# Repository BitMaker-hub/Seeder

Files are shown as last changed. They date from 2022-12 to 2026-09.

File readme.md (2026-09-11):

# SEEDER - Sovereign seed generator

Un dispositivo DIY que te permite crear tus propias semillas de Bitcoin en cuestión
de segundos, sin depender de nadie ni de nada para salvaguardar tus fondos.

Con la SEEDER puedes hacer el proceso **semilla moneda**, generar entropía con
**dados**, y **calcular la última palabra de tu semilla sin esfuerzo**, además de
exportarla mediante un código QR.

Todo ello gracias a la genial idea de @Lunaticoin y mi trabajo.

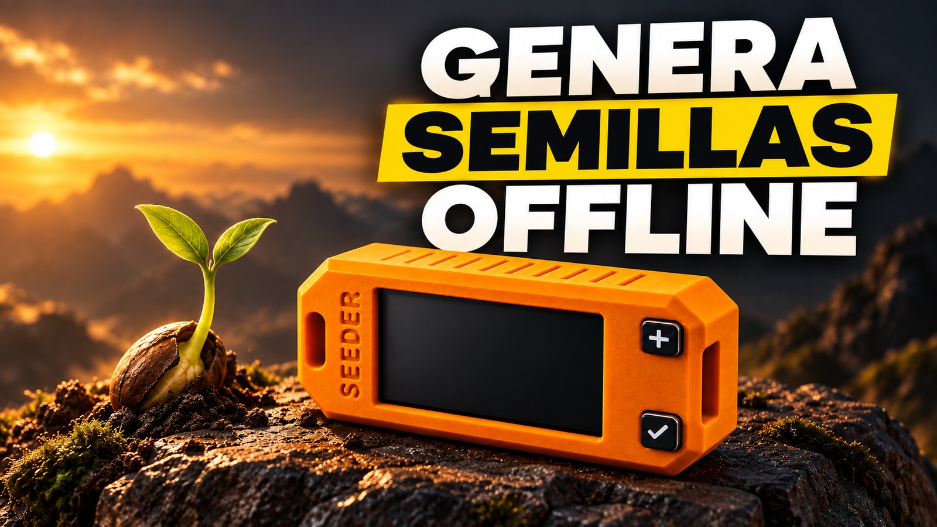
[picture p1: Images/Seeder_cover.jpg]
SEEDER, genera semillas offline


## La SEEDER no genera entropía

Esto es lo que hace distinta a la v2: **el dispositivo no tiene generador de números
aleatorios**. La entropía la pones tú, con una moneda o con un dado, y la SEEDER se
limita a hacer las cuentas de BIP39 delante de ti.

Y esas cuentas las puedes rehacer por tu lado. La SEEDER te enseña la entropía en
hexadecimal en la pantalla `Entropy (hex)`. Con ese hex y cualquier herramienta BIP39
offline obtienes exactamente las mismas palabras. Si no coinciden, tira el aparato.

| Modo | Entradas | Entropía |
|---|---|---|
| Moneda | 128 tiradas (12 palabras) / 256 (24) | los bits, tal cual, sin pasar por ningún hash |
| Dado | 50 tiradas (12 palabras) / 99 (24) | `SHA-256` de los dígitos en ASCII |

El modo dado usa el mismo esquema que la Coldcard, así que puedes verificarlo desde
un terminal:

```bash
printf '3141592653...' | sha256sum
```

Con 24 palabras se usan los 32 bytes del hash; con 12 palabras, los **16 primeros**
(los 32 primeros caracteres del hex). Es lo mismo que hace la Coldcard.

Y el modo moneda no aplica ningún hash: los bits que lanzas **son** la entropía. Eso
te permite además meter una entropía que ya tengas y dejar que la SEEDER te calcule
la última palabra con su checksum.

## Requisitos

Cualquiera de las dos placas:

| Placa | Pantalla | Binario |
|---|---|---|
| LilyGO TTGO T-Display (ESP32) | 240x135 | `seeder-tdisplay-merged.bin` |
| LilyGO T-Display-S3 (ESP32-S3) | 320x170 | `seeder-tdisplay-s3-merged.bin` |

Y un cable USB-C.

Opcionalmente admite una LiPo por el conector JST. La placa no trae interruptor,
pero **sí se puede apagar por firmware**: cómo hacerlo, y qué esperar del consumo
en reposo, está en [HARDWARE.md](HARDWARE.md).

## Instalación

Todo sale de la [última release](https://github.com/BitMaker-hub/Seeder/releases).
Hay dos caminos: uno cómodo y otro comprobable. Elige según lo que te juegues.

### Vía rápida — desde el navegador

Descarga `seeder-firmware-merged.bin` y flaséalo con
[esptool-js](https://espressif.github.io/esptool-js/) en el offset **0x0**.
Un solo archivo, nada que instalar.

> Cómodo, pero estás confiando en que la página te sirvió el binario correcto.
> Para una semilla de verdad, haz también la comprobación de abajo.

### Vía manual — desde el terminal, y verificable

Descarga la release entera, incluido el `SHA256SUMS`, y comprueba que lo que te
has bajado es lo que la CI publicó:

```bash
sha256sum -c SHA256SUMS
```

Flashea:

```bash
esptool.py --chip esp32 --port /dev/ttyUSB0 --baud 460800   write_flash -z 0x0 seeder-firmware-merged.bin
```

Y comprueba que el chip contiene de verdad ese binario:

```bash
esptool.py --port /dev/ttyUSB0 --no-stub verify_flash 0x0 seeder-firmware-merged.bin
```

En Windows el puerto es `COM3` o similar. Ese último paso es el que importa y
está explicado en [SECURITY.md](SECURITY.md): con `--no-stub` la aplicación de la
SEEDER ni se ejecuta, responde el bootloader de la ROM del chip, así que un
firmware manipulado no puede mentir sobre lo que hay en la flash.

## Compilar desde fuente

```bash
pio run -e seeder
```

Las librerías (`uBitcoin`, `TFT_eSPI`) van fijadas dentro de `lib/` a propósito:
un generador de semillas debe compilar igual hoy que dentro de cinco años.

## Controles

Dos botones y nada más. **MOVE** es el de arriba y **OK** el de abajo.

| Dónde estás | MOVE | OK |
|---|---|---|
| Menú y elección de palabras | cambia la opción | acepta |
| Lanzando la moneda | cara | cruz |
| Tirando el dado | 1 → 6 | acepta la tirada |
| Leyendo la semilla | página siguiente | página anterior |
| Última página (`Exit`) | vuelve a la primera | mantener para salir y borrar |

Durante la captura, **mantener OK tres segundos vuelve al menú** y borra lo que
llevaras metido: si te has equivocado en la tirada 40 de 99 no hace falta
desenchufar el aparato. A los ~1,2 s aparece el aviso con una barra que se llena;
si sueltas antes, esa pulsación no cuenta como cara, cruz ni tirada.

## Llevarla a Sparrow

La SEEDER exporta dos QR distintos, y **no dan el mismo poder**:

| Pantalla | Qué lleva | Quien lo escanee |
|---|---|---|
| `Export` | las 12 o 24 palabras | **puede gastar** |
| `Watch only` | el zpub de cuenta | sólo ve el saldo |

**Sólo lectura** — es el que puedes escanear con el ordenador delante:

1. `File > New Wallet…`, le pones nombre y `Create Wallet`.
2. Se abre en *Settings* con **Single Signature** y **Native Segwit (P2WPKH)**
   ya puestos. Déjalos: son justo los de la SEEDER.
3. En *Keystores*, el icono del **ojo**, `Watch Only Wallet`.
4. En la fila `xpub:`, el botón de la **cámara**, y le enseñas el QR.
5. La SEEDER te muestra la huella maestra en esa misma pantalla. Cópiala en
   *Master fingerprint*, que Sparrow lo deja en `00000000` y ese cero acaba
   metido en cada PSBT que construya.
6. `Apply`.

> El botón de QR que hay junto al campo `Descriptor:` **no** sirve para esto:
> con una clave suelta no hace nada y no avisa. Tiene que ser el de la fila
> `xpub:`.

**La semilla**, si de verdad la quieres importar: `BIP39 keystore`, la **flecha
del desplegable** junto a `Use 24 Words`, y ahí dentro `Scan QR…`. No hay botón
visible y no está documentado. Necesita Sparrow **1.7.7 o posterior**.

Pero piénsatelo: meter las palabras en un ordenador conectado tira por tierra
todo lo demás. Para mirar el saldo te basta el zpub.

## Verificación

No te fíes de la SEEDER: compruébala. La pantalla `Entropy (hex)` te enseña los
bytes de los que salieron tus palabras, y con ese hex y cualquier herramienta BIP39
**offline** puedes rehacer las cuentas. Si no coinciden, no uses el aparato.

Hazlo con **tu propia entropía**, no con los vectores publicados: un firmware
malicioso reconoce las tiradas de prueba y se porta bien sólo ahí.

El modelo de amenazas completo, y qué no cubre, está en [SECURITY.md](SECURITY.md).

> La semilla nunca sale del dispositivo ni se escribe en flash: sólo vive en RAM y
> desaparece al desconectarlo. El firmware tampoco imprime nada por el puerto serie.

## TUTORIAL

Tutorial completo en YouTube:

Ver video aquí (https://youtu.be/2K7ztWxtyY8)

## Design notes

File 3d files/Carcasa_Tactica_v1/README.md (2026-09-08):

# SEEDER — carcasa táctica v1

Carcasa para **LilyGO TTGO T-Display (ESP32)** con hueco para batería, cierre por
clips y anilla para colgar. Todas las cotas de la placa están sacadas del STEP
oficial `T-Display.step`, no estimadas.

**Exterior: 30.6 × 66.0 × 17.4 mm** · ~16 g de PLA el juego completo.

## Piezas

| Fichero | Qué es | Cantidad |
|---|---|---|
| `Seeder_CUERPO.stl` | Cuerpo frontal (pantalla, botones, USB, anilla) | 1 |
| `Seeder_TAPA.stl` | Tapa trasera con clips y bolsillo de batería | 1 |
| `Seeder_BOTONES_x2.stl` | Los dos pulsadores (`+` y check) | 1 juego |
| `Seeder_BOTONES_x2_giro_opuesto.stl` | Los mismos con los iconos girados 180° | alternativa |

### Por qué hay dos juegos de botones

El firmware arranca la UI en **landscape** (`setRotation(1)`, 240×135), o sea que
el aparato se lee girado 90° respecto a la carcasa. Los iconos van grabados en esa
orientación, pero según hacia qué lado gires el aparato al usarlo, el check queda
derecho o del revés. Imprime el juego que corresponda; el `+` da igual.

## Impresión (Bambu Lab P1S / P2S / H2S)

| Ajuste | Valor |
|---|---|
| Material | PLA (o PETG si lo quieres más resistente al calor) |
| Boquilla / capa | 0.4 mm / 0.2 mm |
| Perímetros | 3 |
| Relleno | 20 % giroide |
| Soportes | **ninguno** |
| Balsa/brim | no hace falta |

**Orientación en la placa:**

- **Cuerpo**: cara frontal (la de la pantalla) **contra la cama**. Así el grabado
  del SEEDER y los nervios salen limpios, y las cavidades quedan hacia arriba.
  Si usas placa texturizada, la cara vista sale con acabado mate tipo equipo militar.
- **Tapa**: cara exterior contra la cama. Los clips y las paredes de la batería
  quedan hacia arriba, sin voladizos.
- **Botones**: cara vista (la del icono) contra la cama.

Los únicos puentes son el techo de la abertura del USB (12.4 mm) y el de las
cuatro ventanas de clip (7 mm). Ambos los hace cualquier Bambu sin problema.

## Montaje

1. Mete la placa en el cuerpo **por detrás**, con la pantalla mirando a la ventana.
   Apoya sobre la repisa perimetral de 2 mm.
2. Coloca los dos botones por delante, desde fuera. Encajan a presión: la pestaña
   queda atrapada entre la placa frontal y la PCB, así que **no se caen una vez
   cerrada la tapa**.
3. Conecta la batería al JST y colócala en el bolsillo de la tapa. El cable sale
   por el hueco de 11.2 mm del lado del USB.
4. Cierra la tapa presionando hasta oír los cuatro clics.

**Para abrir**: hay una muesca de palanca en el canto del USB. Una uña o una púa
de guitarra bastan.

## Batería

Cabe hasta **21 × 40 × 6.6 mm**. Una LiPo 602040 (500 mAh) entra holgada. Sujétala
con un trozo de cinta de doble cara al fondo del bolsillo para que no baile.

## Comprobado

- Las tres piezas son **watertight** (malla cerrada, lista para laminar).
- Encaje verificado contra los 655 sólidos del STEP de la placa: interferencia
  máxima **0.010 mm**, y sólo en el plano donde la PCB apoya sobre su repisa.
  Se descuenta automáticamente la envolvente de cada componente frontal, así que
  ni el pulsador de reset ni los SMD del borde rozan.
- Los botones llevan 0.05 mm de precarga contra el pulsador SMD: hacen contacto
  sin dejarlo pulsado.

## ⚠️ Verificar antes de imprimir la serie

El STEP de LilyGO **no incluye ni el conector USB ni el módulo ESP32**. Por eso:

- La abertura del USB va deliberadamente holgada: **12.4 mm de ancho × 4.4 de alto**
  (z 4.5–8.9), que vale tanto para micro-USB como para USB-C. **Mide la tuya** y
  ajusta `USB_W`, `USB_Z0` y `USB_Z1` en `seeder_case.py` si quieres que ajuste fino.
- El hueco para componentes traseros es de 3.8 mm, suficiente para el ESP32-WROOM
  (3.1 mm). Si tu placa lleva algo más alto por detrás, sube `BACK_CLR`.

Imprime **una** unidad y prueba el encaje antes de tirar de serie.

## Regenerar / modificar

Todo es paramétrico. Los parámetros están arriba del todo de `seeder_case.py`.

```bash
py -m pip install build123d trimesh manifold3d shapely numpy rtree
```

```bash
py seeder_case.py
```

- `extract_clearance.py` regenera `components.json` desde el STEP (sólo hace falta
  si cambias de placa).
- `fitcheck.py` vuelve a comprobar que la placa no choca con nada.

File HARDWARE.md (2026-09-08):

# La SEEDER con batería

La T-Display admite una LiPo por su conector JST 1.25, pero **no trae interruptor**:
la enchufas y está encendida para siempre. Este documento recoge lo que hay que
saber para montarla con batería, incluida una función de la placa que no está
documentada en ningún sitio.

---

## Sí se puede apagar: PWR_EN es GPIO14

La T-Display tiene un MOSFET que corta la batería, y el ESP32 puede accionarlo.
Sale del [esquemático oficial](https://github.com/Xinyuan-LilyGO/TTGO-T-Display/blob/master/schematic/ESP32-TFT(6-26).pdf),
donde la red `PWR_EN` está en el **pin 17 del módulo, `MTMS/IO14`**:

```
PWR_EN (GPIO14) ──D6──┐
                      ├── R25 10K ──► base Q3 (PMBT3904)     R27 100K a GND
VBUS ─────────────D1──┘
                            colector Q3 ── R26 1K ──► puerta de Q4 y Q6

BAT ──► Q4 (SI2301, canal P) ──► IN del AP2112K-3.3V ──► VDD3V3
              R28 100K entre la puerta y el lado del regulador
```

`Q4` es el interruptor de la batería. Su puerta la manda `Q3`, que conduce si hay
`VBUS` **o** si `PWR_EN` está alto.

En la práctica:

```cpp
pinMode(14, OUTPUT);
digitalWrite(14, HIGH);   // engancha la alimentación al arrancar
...
digitalWrite(14, LOW);    // corta la batería
```

### Dos advertencias

**Por USB no se puede apagar, y esto es seguro.** `D1` mete VBUS directamente en
la base de `Q3`, así que mientras haya cable, `Q3` conduce pase lo que pase con
GPIO14. El corte sólo tiene efecto con la placa alimentada sólo por batería.

**El enganche es flojo, y esto está sin verificar.** `R28` lleva la puerta de `Q4`
al lado del regulador, no al de la batería. Eso hace que la placa arranque sola al
conectar la LiPo, pero también que al soltar `PWR_EN` la puerta suba siguiendo al
propio raíl que está alimentando: puede cortar limpiamente o quedarse en una zona
intermedia y rearrancar. En el repo de LilyGO hay un
[hilo abierto](https://github.com/Xinyuan-LilyGO/TTGO-T-Display/issues/6) de alguien
que reporta justo eso, sin respuesta.

**Si lo pruebas, cuéntanoslo.** Es la clase de dato que no está escrito en ninguna
parte.

---

## La alternativa segura: un interruptor

Para una unidad que va a estar guardada, lo que no falla es un **interruptor
deslizante en el positivo del JST**. Cero consumo, y en un generador de semillas
"apagado" de verdad vale más que "durmiendo". La carcasa de `3d files/` tiene sitio.

---

## Sueño profundo, y por qué aquí importa

Si no cortas la corriente, la otra vía es el *deep sleep* del ESP32, despertando con
un botón. El detalle que casi todo el mundo se salta: **si no apagas la pantalla se
siguen yendo unos 10 mA** aunque el chip duerma. Hay que apagarla a mano:

```cpp
digitalWrite(TFT_BL, LOW);                    // GPIO4, retroiluminación
tft.writecommand(ST7789_DISPOFF);             // apagar el panel
tft.writecommand(ST7789_SLPIN);               // dormir el controlador
esp_sleep_enable_ext0_wakeup(GPIO_NUM_0, 0);  // despertar con OK
esp_deep_sleep_start();
```

Con eso se llega a **~380 µA**, [medidos por la comunidad](https://www.paleotechnologist.net/?p=5041).
Con una LiPo de 500 mAh son unos **55 días** en reposo, frente a dos días si te
olvidas del panel. No es cero: para meses en un cajón, interruptor.

Los dos botones sirven para despertar. Los pines RTC del ESP32 son
[`0, 2, 4, 12-15, 25-27, 32-39`](https://docs.espressif.com/projects/esp-idf/en/stable/esp32/api-reference/system/sleep_modes.html),
y tanto `GPIO0` como `GPIO35` están dentro.

### Y para este aparato en concreto, dormir es borrar

La documentación de Espressif lo dice de las modalidades de sueño profundo: *las CPU,
la mayor parte de la RAM y todos los periféricos digitales se apagan*. Sólo sobrevive
la memoria RTC, y la SEEDER no guarda nada ahí.

O sea que **entrar en sueño profundo destruye la semilla por hardware**, sin depender
de que el `memzero` del firmware esté bien escrito. Para un aparato cuya premisa es
no fiarse del firmware, eso no es un detalle menor.

---

## Un fallo conocido

Hay un [hilo abierto](https://github.com/Xinyuan-LilyGO/TTGO-T-Display/issues/111)
donde, tras descargar la batería del todo, la placa "olvida" que podía despertar por
GPIO y sólo revive con un reset manual. Sin causa identificada. Tenlo presente si
montas una unidad para dejarla guardada mucho tiempo.

---

## Medir la batería

El divisor de tensión de la batería está en **GPIO34** (`ADC_IN` en el pinout de
LilyGO). No lo usamos, pero está ahí si alguien quiere un indicador de carga.

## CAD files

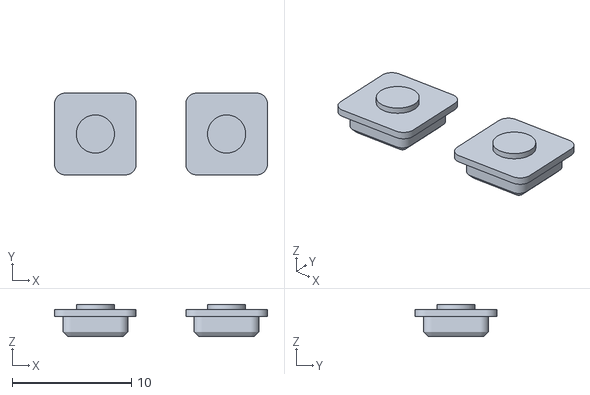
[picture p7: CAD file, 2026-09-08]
3d files/Carcasa_Tactica_v1/Seeder_BOTONES_x2_giro_opuesto.stl
17.9 x 6.85 x 2.70

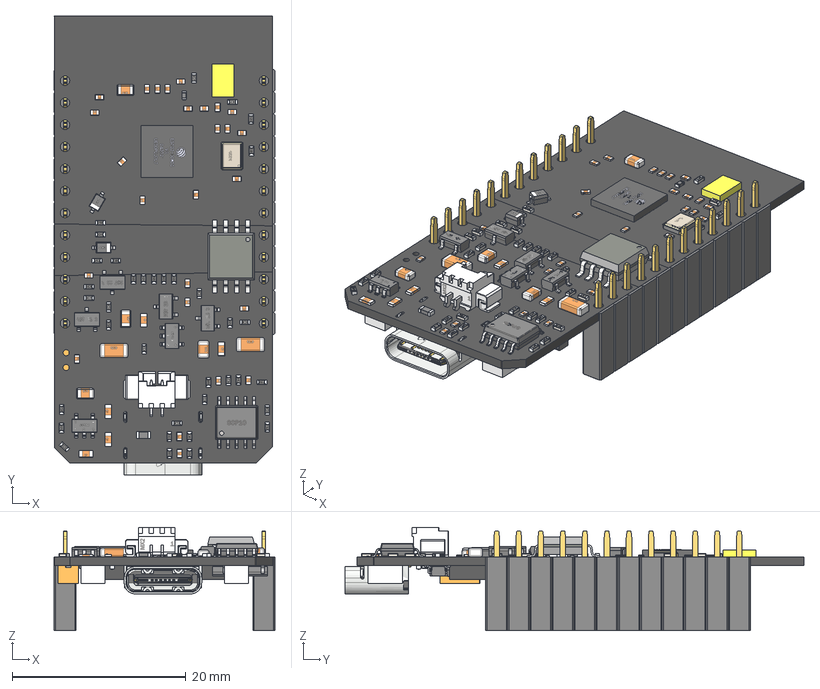
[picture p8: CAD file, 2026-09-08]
3d files/T-Display.step
25.5 x 52.8 x 11.9 mm
Board
User_Library-RES_1005-0402 x 39
SOD323 x 2
C1206 x 2
0402_SMD_Capacitor x 27
SW3dPS-SOIC8_(ATTINY12)
HDR2.54-1P_M x 24
LOGO? x 24
User_Library-SOT23-5_SOT23-5_Connector_Default x 10
User_Library-SOT23-5_SOT23-5_Body_Default x 2
L0402
ESP32
OSC_3225-4
LOGO?0.15
L0603
SOT-23-3 x 7
MOLEX1.25-WS-竘褐 x 2
LOGO?0.25
MOLEX1.25-WS-2P
User_Library-0603_SMD_Capacitor x 7
User_Library-0805_SMD_Capacitor x 4
SOP10_呿极
厚度2.0_宽度0.35的引脚 x 10
Extruded x 5
SOD-123
LOGOﾔｲ｣ｭ｣ｰ.｣ｳ
hmt-usb16f-dip

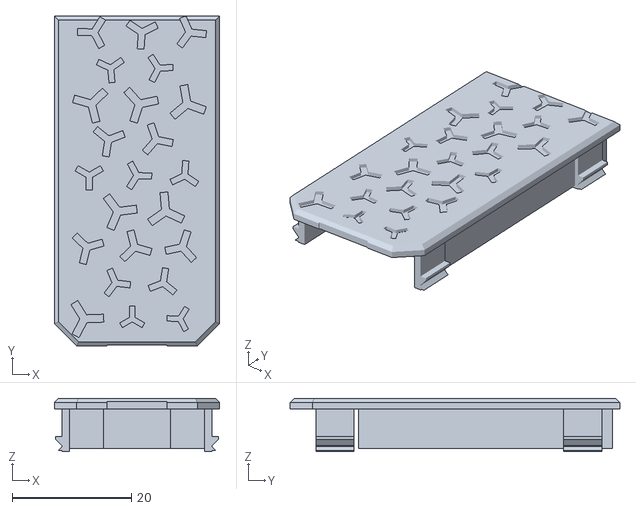
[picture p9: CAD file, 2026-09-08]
3d files/Carcasa_Tactica_v1/Seeder_TAPA.stl
27.7 x 55.3 x 8.90

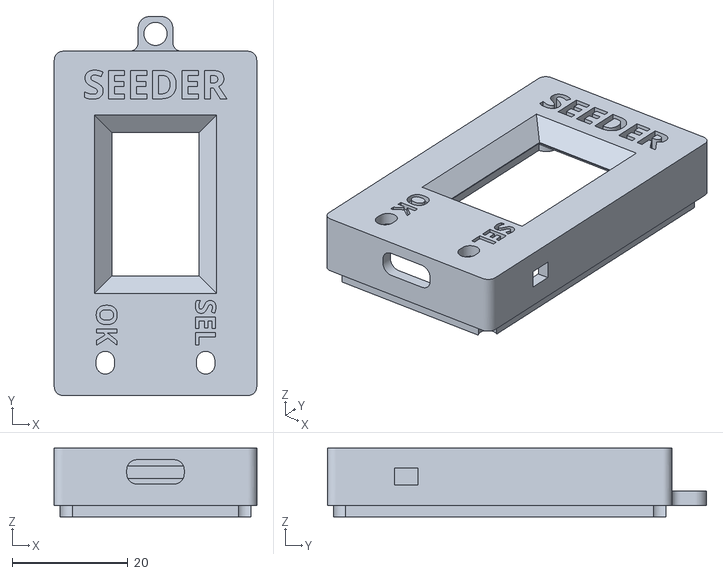
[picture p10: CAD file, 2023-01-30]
3d files/SeederTOP.stl
35.0 x 65.5 x 11.9

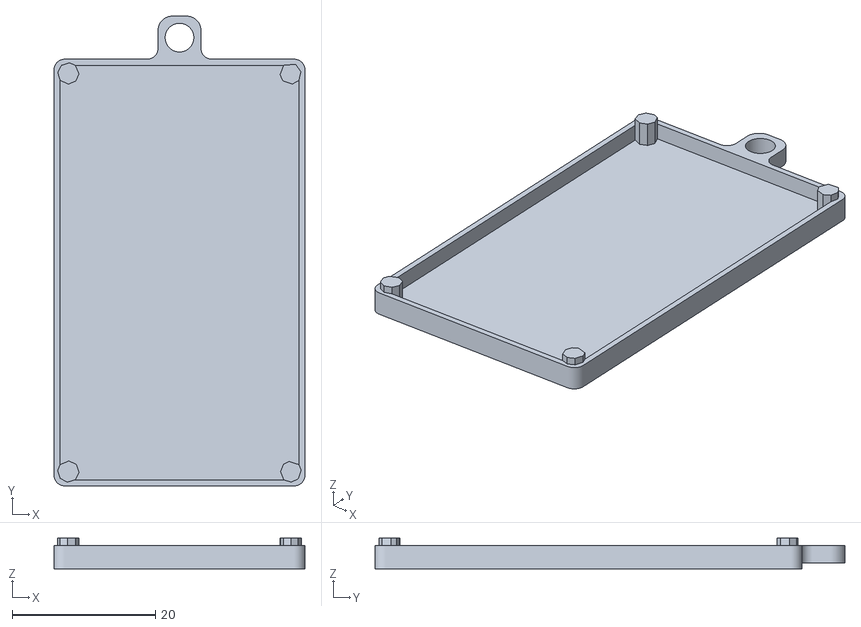
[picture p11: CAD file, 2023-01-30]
3d files/TAPA_SEEDER.stl
35.0 x 65.5 x 4.30

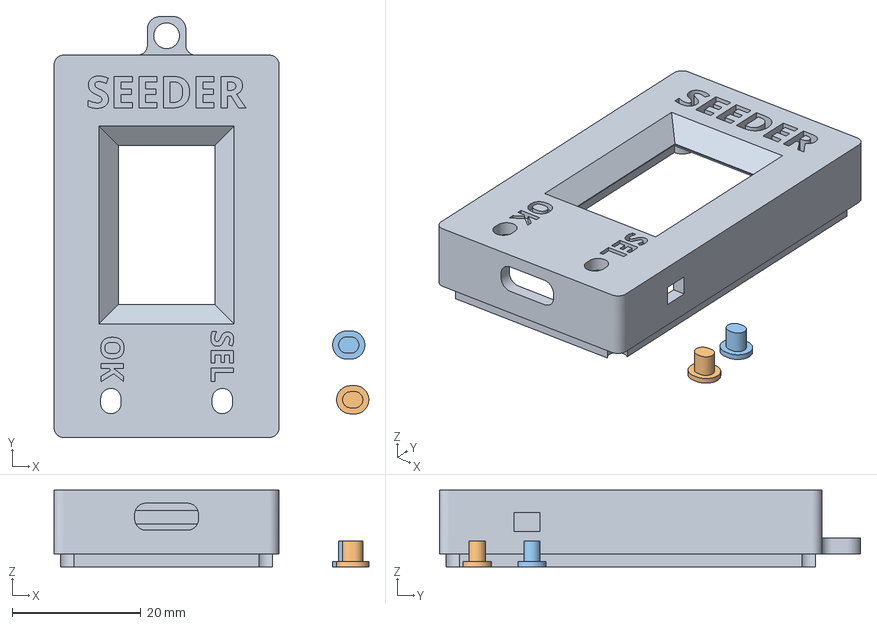
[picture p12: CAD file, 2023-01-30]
3d files/AG_SeederALL.3mf
49.0 x 65.5 x 11.9 mm
SeederTOP.stl
button-2.stl
button-3.stl

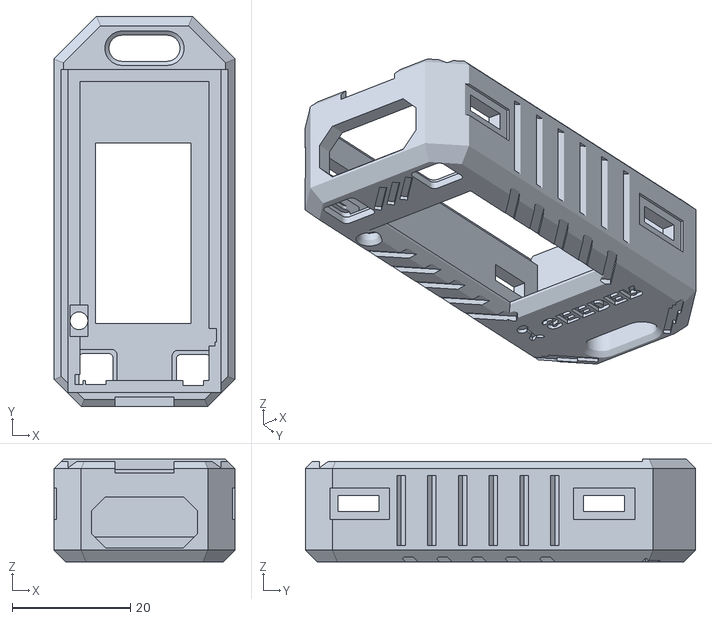
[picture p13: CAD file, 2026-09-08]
3d files/Carcasa_Tactica_v1/Seeder_CUERPO.stl
30.6 x 66.0 x 17.4

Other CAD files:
3d files/Carcasa_Tactica_v1/Seeder_BOTONES_x2.stl

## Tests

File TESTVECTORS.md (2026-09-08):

# Vectores de prueba

Cómo comprobar que tu SEEDER hace las cuentas bien, sin fiarte de ella.

Ninguno de estos vectores es una semilla que debas usar: son entropías
degeneradas, elegidas justamente porque se pueden reproducir a mano.

## Modo moneda — los bits son la entropía

En el modo moneda no hay hash: los bits que lanzas **son** la entropía. Así que
si sacas siempre cruz, la entropía es todo ceros, y eso da el vector de prueba
más conocido de BIP39. Cualquier herramienta del mundo te dará lo mismo.

**12 palabras — 128 tiradas, todas cruz**

```
Entropy (hex)  00000000000000000000000000000000
abandon abandon abandon abandon abandon abandon
abandon abandon abandon abandon abandon about
```

**24 palabras — 256 tiradas, todas cruz**

```
Entropy (hex)  0000...0000  (32 bytes a cero)
abandon x23 art
```

## Modo dado — SHA-256 de las tiradas

El dado siempre vuelve al 1 después de aceptar una tirada, así que **pulsando
sólo OK** metes una tirada de 1 cada vez. 50 veces para 12 palabras, 99 para 24.

Toques cortos: mantener OK más de un segundo no cuenta como tirada, saca el aviso
de `START OVER` y a los tres segundos vuelve al menú.

**12 palabras — 50 unos**

```
$ printf '11111111111111111111111111111111111111111111111111' | sha256sum
3dac51a65ec9fcfc409a1b5f1defe92ba723843118ea511971ab46b36859495f

Entropy (hex)  3DAC51A65EC9FCFC409A1B5F1DEFE92B     <- los 16 primeros bytes
diet glad hat rural panther lawsuit act drop gallery urge where fit
```

**24 palabras — 99 unos**

```
$ printf '111111111111111111111111111111111111111111111111111111111111111111111111111111111111111111111111111' | sha256sum
fa098eb852b2660348b21bb00ad03a49cc177ea07ebe34f46b40baa85313525e

Entropy (hex)  FA098EB852B2660348B21BB00AD03A49CC177EA07EBE34F46B40BAA85313525E
wheel erase puppy pistol chapter accuse carpet drop quote final attend near
scrap satisfy limit style crunch person south inspire lunch meadow enact tattoo
```

## Y con tu semilla de verdad

El mismo procedimiento vale para la semilla que vayas a usar, sin publicarla:
apunta el `Entropy (hex)` que te enseña la SEEDER, mételo en cualquier
herramienta BIP39 **offline** y comprueba que salen las mismas palabras.

Si no salen, no uses el aparato.

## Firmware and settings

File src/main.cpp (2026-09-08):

#include <Arduino.h>
#include "gpio.h"
#include "btc.h"
#include "workflow.h"
#include "GlobalVARS.h"

sWallet myWallet;
sButton btnMove(PIN_MOVE);
sButton btnSelect(PIN_SELECT);
  
void setup() {

#if SEEDER_DEBUG
  Serial.begin(SERIAL_BAUD);                  // UART only exists in debug builds
#endif
  Init_TFT();                                   // Init TFT wallet
  myWallet.State = STATE_INITMENU;
}


void loop() {
  
  while(true){
    /***** Check button state ******/
    btnMove.check();
    btnSelect.check();

    /***** Print menu options ***********/
    switch(myWallet.State){
      case STATE_INITMENU:      doInitMenu(); break;
      case STATE_WORDS:        doMenuWords(); break;
      case STATE_SEED:        doShowSeed(); break;
      case STATE_COINSEED:    doCoinSeed(); break;
      case STATE_DICESEED:    doDiceSeed(); break;
    }
    delay(10);
  }
}

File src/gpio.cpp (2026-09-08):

#include "GlobalVARS.h"
#include "gpio.h"
#include "workflow.h"
#include "ui/ui.h"
#include <TFT_eSPI.h> // Graphics and font library for ST7789 driver chip

/**********************🍃 GLOBAL Vars *******************************/
TFT_eSPI tft = TFT_eSPI();  // Invoke library, pins defined in User_Setup.h
extern sWallet myWallet;
extern sButton btnMove;
extern sButton btnSelect;

/*****************🍃 TFT WORK *********************/

void Init_TFT(void){

#ifdef PIN_POWER_ON
  /* La T-Display-S3 alimenta sus periféricos desde este pin. Si no se pone
     alto ANTES de arrancar el panel, la pantalla no enciende y la placa
     parece muerta: es el fallo clásico de esa placa. */
  pinMode(PIN_POWER_ON, OUTPUT);
  digitalWrite(PIN_POWER_ON, HIGH);
  delay(20);
#endif

  tft.init();
  tft.setRotation(1);
  tft.setSwapBytes(true);   // orden de bytes al volcar imágenes

  ui::splash();

  myWallet.entropySrc = coinEntropy;
  drawInitMenu();
}

/*****************🍃 BUTTON DETECTION *********************/

sButton::sButton(byte bPin){        //Constructor
    pin = bPin; pinMode(pin, INPUT);
    antState = HIGH; longFired = holdFired = false;
    msecLst = msecEdge = 0; clickState = None;
}
void sButton::init(void){  pinMode(pin, INPUT); }     // Init pushbutton pin
int sButton::click(void){  return clickState; }
void sButton::forceClick(void){ clickState = ForcedClick;} //Generates one click loop

//Cuanto lleva pulsado ahora mismo. Cero significa suelto, asi que sirve
//igual para dibujar el progreso de un mantenido y para saber si sigue ahi.
unsigned long sButton::heldMs(void){
    if(!msecLst) return 0;
    const unsigned long h = millis() - msecLst;
    return h ? h : 1;               //0 esta reservado para "suelto"
}

void sButton::check(void)
{
    const unsigned long ButDebounce  = 25;
          unsigned long msec = millis();

    if(clickState == ForcedClick){ clickState = SingleClick; return; }
    clickState = None;

    byte but = digitalRead(pin);

    if(but != antState){
        if(msec - msecEdge < ButDebounce) return;   // bounce, ignore the edge
        msecEdge = msec;
        antState = but;

        if(but == LOW){                             // pressed
            msecLst = msec ? msec : 1;
            longFired = holdFired = false;
        }else{                                      // released
            //Click reported on release, so holding the button never turns two
            //presses into one and no input is ever swallowed
            if(msecLst && !longFired){ clickState = SingleClick; DBGLN("SingleClick"); }
            msecLst = 0;
        }
        return;
    }

    //Still held: LongClick fires once and suppresses the click on release.
    //HoldClick comes later on that same press, so a screen armed by LongClick
    //has something to fill up to and letting go still backs out of it.
    if(but != LOW || !msecLst) return;
    const unsigned long held = msec - msecLst;

    if(!longFired && held > BTN_LONG_MS){
        longFired = true;
        clickState = LongClick;
        DBGLN("LongClick");
    }else if(longFired && !holdFired && held > BTN_HOLD_MS){
        holdFired = true;
        clickState = HoldClick;
        DBGLN("HoldClick");
    }
}

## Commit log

2023-01-30 Adding 3dFiles
    - Added 3dFiles to project
    [AG_SeederALL.3mf, SeederTOP.stl, TAPA_SEEDER.stl]
2026-09-08 fix(coin): 24-word lockup, stale entropy and off-by-one
    - nBCoinEntropy was uint8_t; 24 words needs 256 bits, so the completion
    check (n == 256) could never be true and the counter wrapped forever.
    - entropy[] is global and was never cleared, so a second coin seed in the
    same session mixed in the bits of the previous one. Wiped on entry.
    - Bits were combined with + instead of |=, which carried into neighbouring
    bits once the array was dirty.
    - The completion check ran before the counter increment, so the device asked
    for one extra flip after the on-screen counter had already reached 0.
2026-09-08 security: never print the seed or the entropy over serial
    The published bin/ firmware printed the mnemonic, the raw hex entropy and
    every coin bit over UART0 at 115200. The T-Display is normally powered from
    a PC over USB, so a seed generated while plugged in was readable by anything
    listening on the COM port.
    Those prints are removed outright, not gated: a flag left at 1 by accident is
    exactly how they shipped. SEEDER_DEBUG only enables button traces and is the
    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
2026-09-08 feat: dice (D6) entropy mode
    Takes over the slot the on-device RNG used to occupy in the main menu.
    MOVE dials 1-6, SELECT accepts the roll; 50 rolls for 12 words, 99 for 24,
    matching Coldcard so a user can cross-check both devices.
    Entropy = SHA-256 over the ASCII digits of the rolls, exactly Coldcard's
    scheme, so it is reproducible with printf '3141...' | sha256sum.
    Adds a page showing the hex entropy the seed was derived from (both modes):
    that hex plus any offline BIP39 tool reproduces the words without trusting
    the SEEDER. Also replaces the forceClick-to-repaint idiom in the menus with
    plain draw functions, and makes the header step counter follow the real
    number of pages instead of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
    [gpio.cpp]
2026-09-08 feat!: drop the on-device RNG
    BREAKING: the SEEDER no longer generates entropy on its own. Coin and dice
    are the only two sources, and both are produced and verifiable by the user.
    esp_random() behind bootloader_random_enable() was a sound choice, but it
    still asks the user to trust that the silicon did what the firmware claims.
    That is exactly the assumption the Coldcard entropy incident invalidated,
    and it is not an assumption this device needs to make: with 128 or 256 bits
    of physical entropy in hand, the only thing left to trust is SHA-256 and
    BIP39, and both are reproducible offline from the hex the device shows.
    [gpio.cpp]
2026-09-08 build: PlatformIO layout and reproducible release binaries
    Moves the sketch to src/ and the vendored libraries to lib/, drops the two
    that were never used (ArduinoJson, and a QRCode copy duplicated by
    src/qrcoded.c), and adds a CI job that builds the firmware, merges the four
    images into one file flashable at 0x0 and publishes it with its SHA256SUMS
    on every tag.
    Removes bin/: those binaries are the ones that print the seed over serial,
    and a 16MB vendored Windows flashing tool nobody needs now that the tutorial
    is one file in esptool-js. Releases replace them.
    The point of the CI is not convenience. A seed generator whose binary cannot
    be traced back to its source is asking for the same t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
    [gpio.cpp, main.cpp]
2026-09-08 docs: test vectors to audit the device against
    The all-tails coin case lands on the canonical all-zeros BIP39 vector, so
    anyone can check the maths against a tool they already trust. The dice case
    is reproducible with sha256sum because the die resets to 1 after each roll,
    so pressing OK 50 times enters fifty 1s.
2026-09-08 fix(input): report clicks on release, drop double-click detection
    Two presses closer than 250ms were merged into one DoubleClick, and nothing
    in the firmware ever handled DoubleClick, so the second press was silently
    discarded. During entropy capture that means the user rolls a 3 and a 5,
    presses twice, and only the 3 goes in - a wrong seed with no warning.
    Clicks are now reported on the release edge with a 25ms debounce, so presses
    can be as fast as the user likes. LongClick drops to 1.2s (5s felt broken)
    and suppresses the click on release so a hold never also counts as a press.
    [gpio.cpp]
2026-09-08 fix(dice): roll digits landed on the header cursor, not the roll line
    displayHeader() does setCursor(4,14) and prints, so it left the cursor at the
    top of the screen. appendRollDigit() relied on the cursor surviving between
    calls, so only the first digit (which sets the cursor itself) landed on the
    roll line and every later one was drawn on the same spot over the 'S' of the
    SEL hint - which is exactly the glyph that looked corrupted on screen.
    The coin path never hit this because the original code saved and restored the
    cursor by hand around displayHeader; that is what CursorX/CursorY were for.
    Fixed at the source: displayHeader now restores the caller's cursor, and both
    capture screens de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
2026-09-08 feat: wipe the seed from RAM on exit, and label the dice icon
    Leaving the seed pages now overwrites the words, the entropy hex, the zpub,
    the raw entropy bytes and the dice rolls. Assigning "" to an Arduino String
    is not enough: it only sets the length to zero and leaves the characters in
    the heap buffer, so they are overwritten in place first. uBitcoin already
    memzeroes the private key and chain code in ~HDPrivateKey.
    The exit page says so now, because it is true.
    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
2026-09-08 docs: threat model
    Says what the device protects, what it does not, and how to check it without
    taking our word for it. Documents two absences that would otherwise look like
    oversights: no firmware hash on screen (self-attestation is circular) and no
    flash encryption (nothing secret to protect, and it would break verify_flash).
    Lists the residual risks too, including the one nothing here covers: a tampered
    firmware that returns the right words and leaks them over the radio.
2026-09-08 feat(ui): split drawing into its own layer and adopt the Rail design
    workflow.cpp no longer touches a pixel. It keeps the state machine and calls
    ui::menu(), ui::diceUpdate(), ui::mnemonic()... while src/ui/ owns everything
    visual: theme.h holds the palette and the metrics, ui.cpp holds the widgets
    (die, caret, bar, rail, wordCard) and the screen composition.
    Swapping the look, or the board, is now swapping that layer - which is the
    same seam the T-Display-S3 port needs, so this is not throwaway work.
    The design itself:
    - The solid green header bar is gone from the capture and seed screens. It was
    the single most dated element. A small caps label, a step counter and a hair
    rule replace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
    [gpio.cpp]
2026-09-08 feat(ui): words and address at double size, same typeface
    With the 5x7 font at size 1 the twelve words filled two of seven available
    lines: legible but small for something you read at arm's length while writing
    it down. The same font at size 2 gives 18 characters per line and four lines.
    One typeface, two sizes - hierarchy rather than a mix. Chrome and long public
    strings (zpub) stay at size 1; the mnemonic and the receive address, the two
    things a user copies by hand, go to size 2.
2026-09-08 fix(ui): legibility audit of every screen
    Measured against the real font metrics rather than by eye:
    - The 12/24 cards used FMB24, 28px per digit: '12' is 56px inside a 54px
    card, so the digits touched the frame. FMB18 is 42px in a 60px card.
    - The mnemonic ran as flowing lines. Twelve eight-letter words need six
    lines, and the sixth started at y=134 on a 135px screen - off the bottom.
    It is now a fixed 6x2 grid, numbered, so twelve words always fit whatever
    they measure, and you do not have to count them while copying.
    - The entropy hex was size 1 and unbroken, which was unreadable on the panel.
    Eight bytes per row at double size, alternating colour.
    - The zpub was 111 base58 cha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
2026-09-08 polish: exit screen, and centre the zpub QR
    The zpub QR sat 6px under the header with 27px of air below it. Now centred
    in the space the header leaves.
    The exit screen was three lines of text and nothing else, which read as an
    afterthought on the one page where the user is about to walk away from a seed
    they may not have written down. It now:
    - Uses a rule with the label inset instead of the usual header, so the page
    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
2026-09-08 feat(ui): list menu with the brand header restored
    Three interfaces, not one: the menu is brand (solid green, black ink), the
    capture screens are work (wide rail with text) and the seed pages are reading
    (hairline rule). The green bar is what separated the first from the others,
    so it comes back - it was carrying more weight than it looked.
    The rail stays but narrow and symbolic: two opposed carets to move, a check
    to confirm. The two buttons read on their own there and the enclosure labels
    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
2026-09-08 fix(ui): coin drawn on edge, tighter pips, and a label that stopped smearing
    The coin was a 2:1 reduction of the 62px bitmap and the leaf inside turned to
    mush at that size - it read as a blob in the middle of a circle. It is drawn
    now: an elliptical face and the rim beside it with its ridges, all primitives,
    so it tints like the die and does not depend on shrinking artwork.
    Die pips move from 1/6, 3/6, 5/6 of the side to 0.22, 0.50, 0.78. The corner
    ones were sitting on the edge.
    And a real bug: on the coin screen BITS LEFT sat right after the number, so
    going 100 -> 99 shifted it left, and the rectangle that cleared it covered
    y 40..50 while the text occupies 46..54 - the bottom four row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
    [brand.h]
2026-09-08 feat: version and commit on the splash, plus final audit fixes
    The boot screen shows v2.0.0 and the short commit, injected from git at build
    time by scripts/version.py (marked with * when the tree is dirty). It is a
    label so you can tell which board carries what, not a proof of anything - a
    tampered firmware prints whatever it likes. SECURITY.md now says so where it
    explains why there is no firmware hash on screen.
    Restores the moving BITS LEFT label: the complaint was the smear, not the
    movement. It follows the number again, and the clearing rectangle now covers
    y 44..56 against text that occupies 46..53 - the previous one stopped at 50,
    which is why the bottom rows of the old label surviv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
2026-09-08 docs: how to run the SEEDER on a battery
    The T-Display has no power switch, but it does have a battery cut-off MOSFET
    the ESP32 can drive, and it is documented nowhere - the question has been open
    in LilyGO's own repo for years with no answer.
    Read off the official schematic: PWR_EN is module pin 17, MTMS/IO14, so
    GPIO14. It feeds the base of Q3 through D6, and Q3 drives the gate of Q4, the
    SI2301 sitting between the battery and the AP2112K regulator.
    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
2026-09-08 docs: two flashing paths, convenient and verifiable
    The one-click browser route through esptool-js stays, but it is now labelled
    for what it is - you are trusting that the page served you the right binary.
    Beside it, the terminal route: check SHA256SUMS against the release, flash,
    then verify_flash --no-stub to prove the chip holds it.
    Splitting them matters for this device. Someone trying it out can take the
    easy path; someone putting savings behind the seed has the steps that do not
    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
    [T-Display.step]
2026-09-08 feat: support the LilyGO T-Display-S3
    Same logic, same crypto, same test vectors on both boards. What changes is
    src/boards/ and the screen size, and the UI layer scales itself.
    The composition was designed on 240x135, so rather than maintain a second
    layout every literal coordinate now goes through SX()/SY() and the bigger
    board reproduces the same design scaled. The two axes scale differently
    (320/240 = 1.33 against 170/135 = 1.26) so they scale separately, not by one
    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
    [Seeder_BOTONES_x2.stl, Seeder_CUERPO.stl, Seeder_TAPA.stl]
2026-09-08 fix(ui): size the QR from the mnemonic instead of pinning version 11
    The QR was hardcoded to version 11, 61 modules, which holds 321 bytes. A
    24-word mnemonic is 155 characters and a 12-word one is 67, so it was always
    drawing far more modules than the data needed - and module size is the only
    thing that decides whether a camera locks on.
    Picking the smallest version that fits, and then the largest pixel-per-module
    that fits the height, changes it to:
    T-Display 12 words 41 modules at 3px (was 61 at 2px)
    T-Display 24 words 49 modules at 2px, 9 modules of quiet zone
    T-Display-S3 12 words 41 modules at 3px, 7 modules of quiet
    T-Display-S3 24 words 49 modules at 3px, 3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
    [Seeder_BOTONES_x2.stl, Seeder_BOTONES_x2_giro_opuesto.stl, Seeder_CUERPO.stl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]
2026-09-08 feat(ui): hold OK for three seconds to start over
    Durante la captura no habia forma de volver atras salvo desconectar la
    placa, y equivocarse en la tirada 40 de 99 obligaba a repetirlo todo.
    Mantener OK vuelve al menu y borra lo capturado.
    El aviso se arma con el LongClick que ya existia a 1200 ms en vez de con
    un contador propio, porque ese evento es el unico que anula el click de
    la suelta: con un umbral nuevo mas corto, soltar a medias habria metido
    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
2026-09-09 fix(build): one source for the version, v2.1.1 shipped saying V2.1.0
    La version vivia en dos sitios de platformio.ini: custom_version, que solo se
    usa para una traza del log de compilacion, y -DSEEDER_VERSION, que es la que
    entra de verdad en el binario y la que pinta el splash.
    Al publicar la 2.1.1 se subio la primera y no la segunda, asi que los binarios
    de esa release arrancan diciendo V2.1.0. El numero que se ve venia justo del
    que nadie tocaba.
    Se quita el -D y la inyecta scripts/version.py desde custom_version, junto al
    hash del commit que ya inyectaba. Con una sola fuente no pueden volver a
    separarse. Verificado en los dos binarios: ahora llevan la version correcta.
    La etiqueta es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
2026-09-09 fix(ui): the export QR was inverted and unreadable by most Android scanners
    Los modulos oscuros se pintaban en blanco y el fondo negro hacia de zona
    tranquila, asi que el codigo salia en negativo. La norma ISO/IEC 18004
    contempla esa inversion pero no obliga a los lectores a soportarla, y en la
    practica no la soportan los que mas se usan: ZXing en Java no lo intenta salvo
    que se le pase la pista ALSO_INVERTED, y zxing-android-embedded -el envoltorio
    que monta la mayoria de apps Android- trae setScanInverted desactivado por
    defecto. La camara de iOS si los lee, de ahi que el fallo pareciera aleatorio.
    Comprobado con un decodificador de verdad, no a ojo: el codigo anterior no se
    leia ni sin d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
